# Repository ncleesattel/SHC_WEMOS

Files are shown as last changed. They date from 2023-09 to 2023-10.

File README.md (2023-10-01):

# SHC_WEMOS
This is a handheld controller for TeenAstro.  
See also [Link to TeenAstro Wiki](https://groups.io/g/TeenAstro/wiki) and [link to TeenAstro github](https://github.com/charleslemaire0/TeenAstro)   
  
It features a 3.3V OLED 2.42" display, a joystick together with the WEMOS D1 mini MCU.  
The associated pcb can be ordered at JLCPCB fully assembled with smd parts and JST XH connectors.  
This reduces the amount of soldering to a minimum.  
  
I also provide a design of an OLED pcb, that does not require smd soldering for the I2C use compared to the DIYmore pcb.  
Costs for the separate OLED pcb are about 3x, which makes it interesting only for hobbyists who want to avoid the smd solder.

## recommendations
* You’ll need to be able to solder a connection using a pinheader between the two pcbs.
* You’ll also need the soldering iron to melt the Ruthex nuts into place.
* The 3D prints do not need supports. Depending on your printer you may need to scale by 1.015 to account for thermal shrink.
* The cable length should be properly sized. The case does not have much room to accommodate long cables, however short cables make assembly and disassembly more difficult.
* Although the JST XH connectors can be attached to the cables without a crimp tool, I would highly recommend one for ease of life. You can thank me later.
*Check the functionality and connector sequence/polarity prior to assembly.

## components needed for build
* PCB group
  * pcb incl. smd parts of SHC
  * pcb for OLED 2.42“. Either mine with switches for I2C or DIYmore incl. smd modification
  * OLED 2.42“ display
  * metal bracket to attach OLED display to OLED pcb
* 3D print group
  * 3d print for pcb to display spacer
  * 3d print of bottom part
  * 3d print of top cover
  * Ruthex M3 nuts 2x
* Switches and cables
  * APEM 1000 joystick
  * APEM 1212 switch for shift
  * RAFI switches for focusser
  * SAL8 connector
  * JST XH connectors

## which files are needed for the...
* pcbs
  * SHC pcb --> jlcpcb folder
  * OLED pcb --> separate repository
* 3D prints
  * SHC bottom case --> models folder
  * SHC top case --> models folder
  * SHC display to pcb spacer --> models folder
 
 ## associated CAD files
The CAD files have been mostly created in Fusion 360 with OEM parts imported where available.

## approximate cost
The cost is calculated for a single SHC, assuming the pcb cost of 5 can be shared.
Shipping costs are included for 2x JLCPCB and 1x Reichelt.

| Parts | Cost |
|---|---|
| WEMOS D1 mini | 6€ |
| 3d printed parts | 40€ |
| SHC pcb | 8€ |
| OLED pcb | 8€ |
| OLED with frame | 18€ |
| APEM joystick | 32€ |
| RAFI and APEM switches | 9€ |
| Remainder | 10€ |
| Total | 131€ |

Depending on if you have access to a 3d printer and can share the pcb cost, you're looking the following range:
minimal build cost 90€ (own 3d printer and can share pcb cost)
maximal build cost 180€ (have to order the 3d case stls and cannot share pcb cost)

## pictures of the SHC
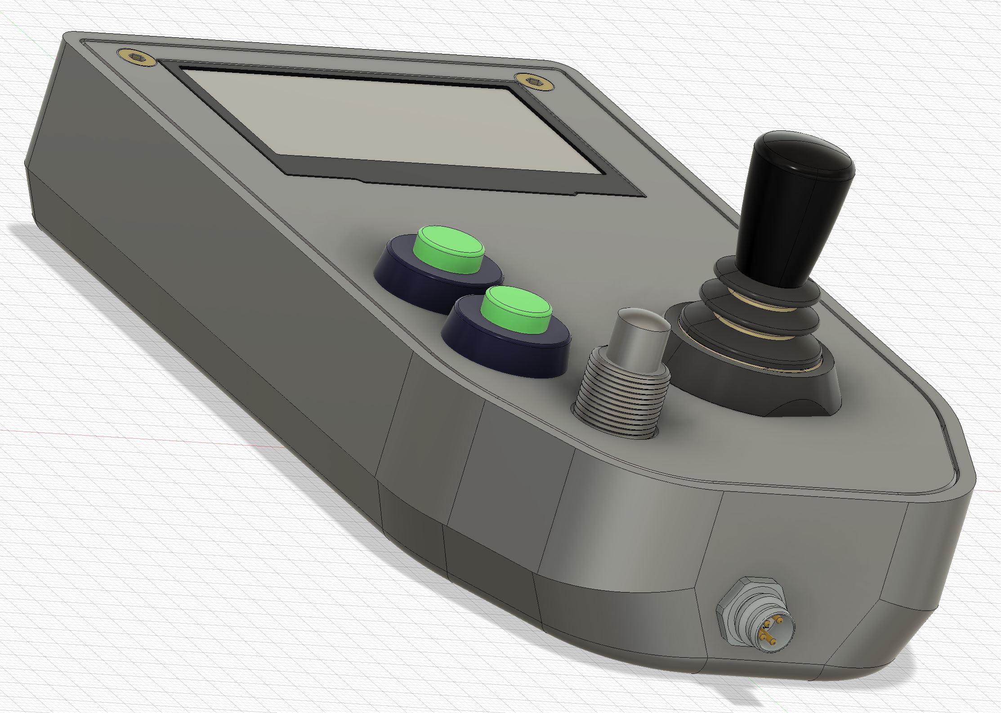
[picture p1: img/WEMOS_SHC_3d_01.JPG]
SHC_WEMOS 3D view WEMOS_SHC_3d_01


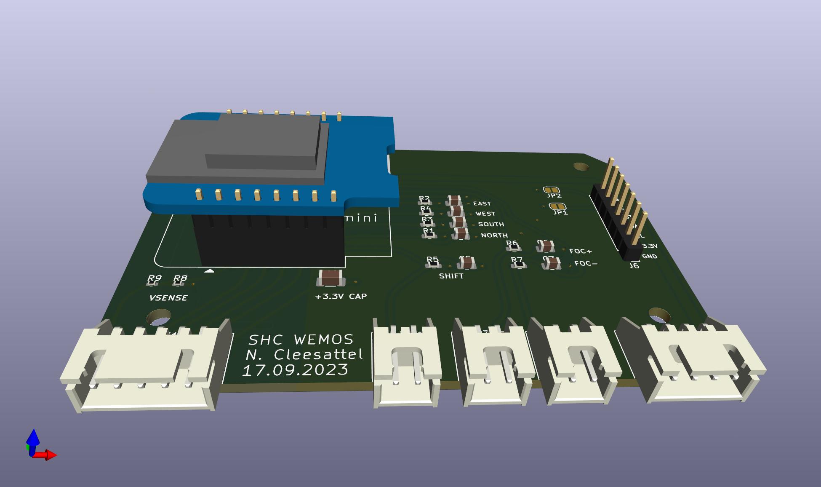
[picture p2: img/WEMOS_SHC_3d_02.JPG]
SHC_WEMOS pcb view WEMOS_SHC_3d_02


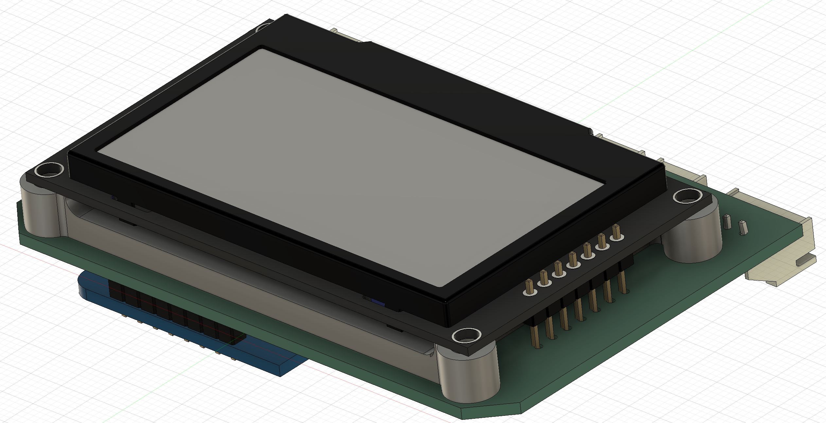
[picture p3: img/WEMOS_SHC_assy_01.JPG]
SHC_WEMOS assembly step 01 WEMOS_SHC_assy_01


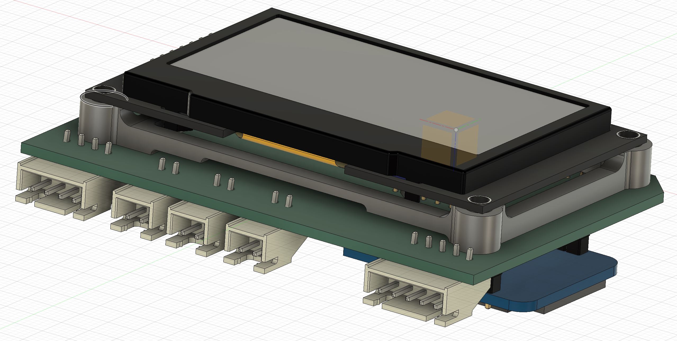
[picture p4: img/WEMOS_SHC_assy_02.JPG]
SHC_WEMOS assembly step 02 WEMOS_SHC_assy_02


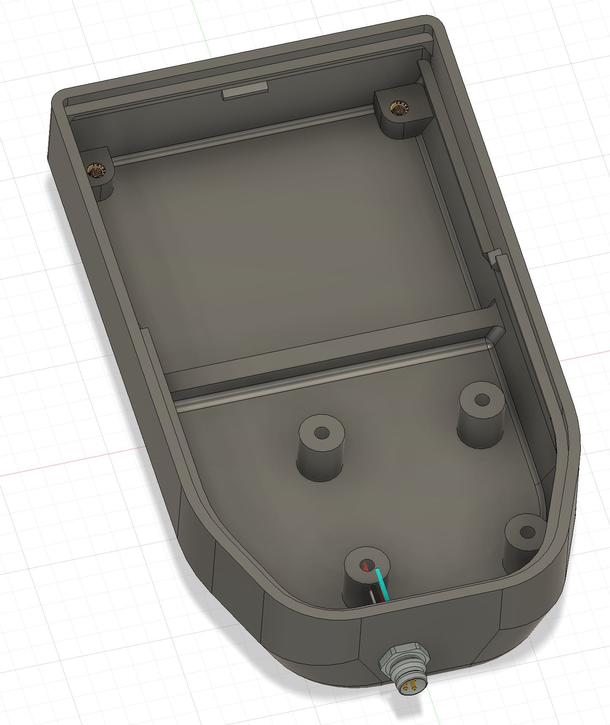
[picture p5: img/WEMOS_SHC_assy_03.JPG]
SHC_WEMOS assembly step 03 WEMOS_SHC_assy_03


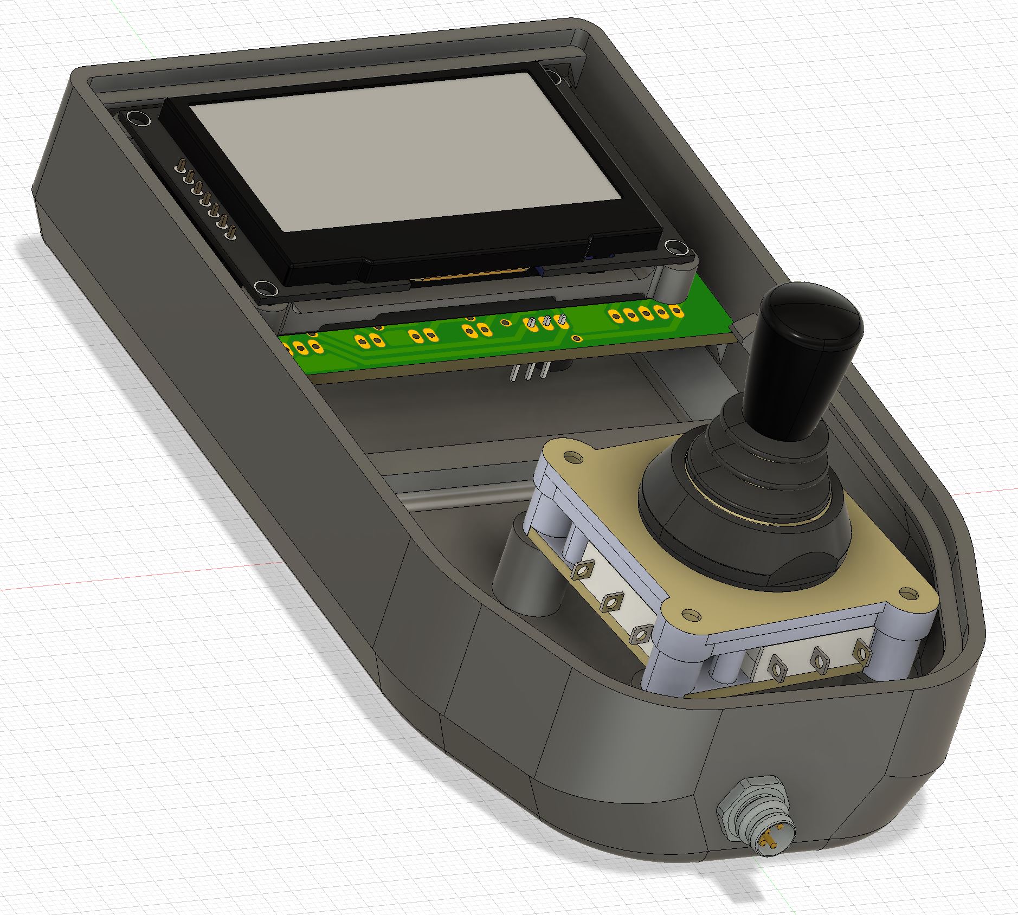
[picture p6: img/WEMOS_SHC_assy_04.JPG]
SHC_WEMOS assembly step 04 WEMOS_SHC_assy_04


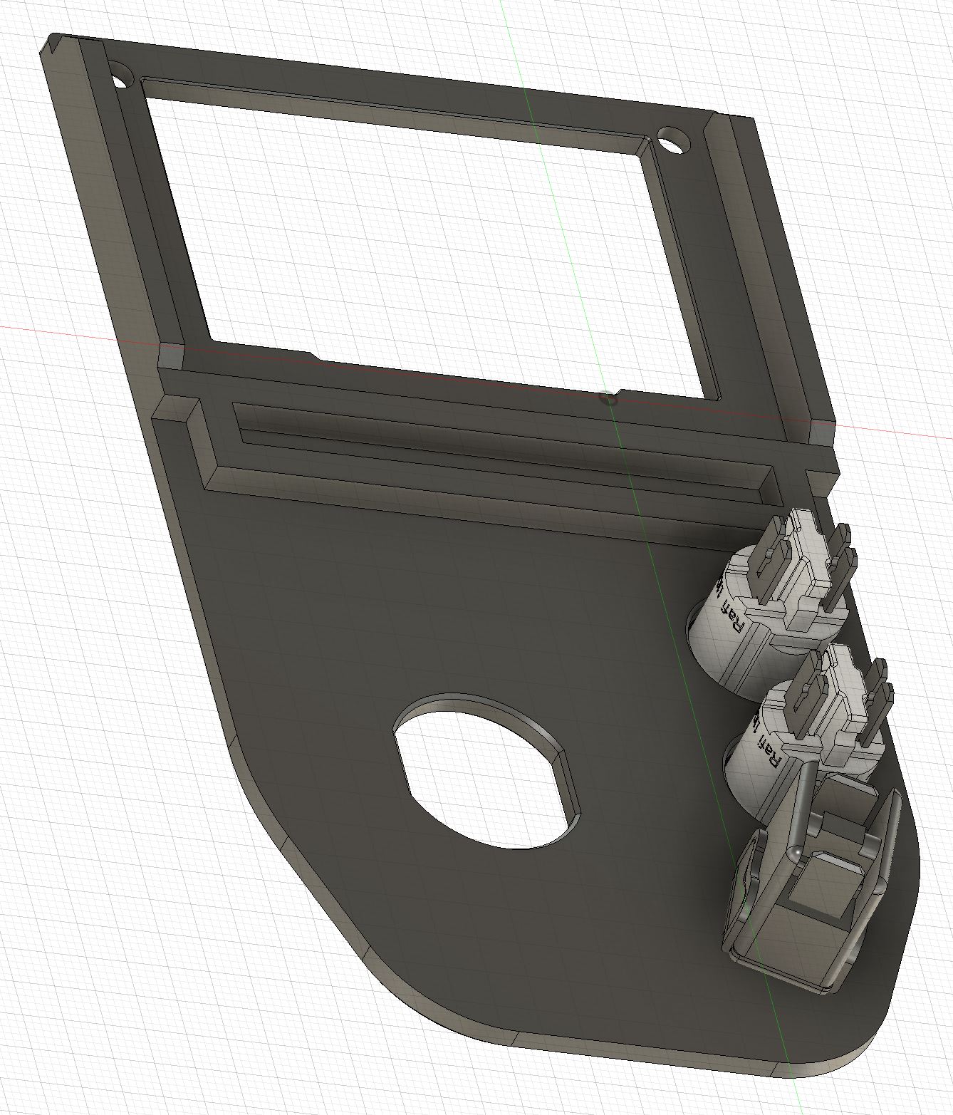
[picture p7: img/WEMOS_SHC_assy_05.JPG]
SHC_WEMOS assembly step 05 WEMOS_SHC_assy_05


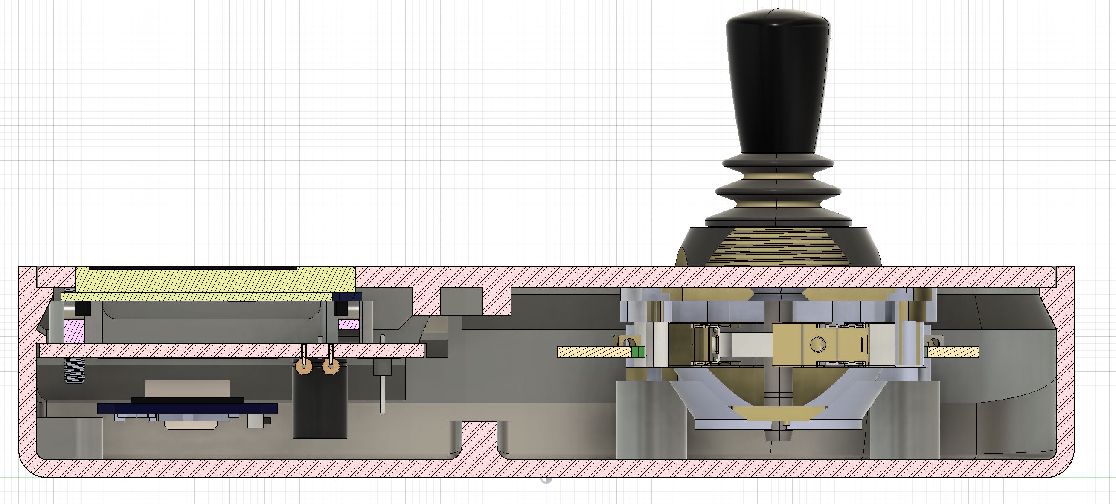
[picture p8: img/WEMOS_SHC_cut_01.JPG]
SHC_WEMOS side view cut WEMOS_SHC_cut_01


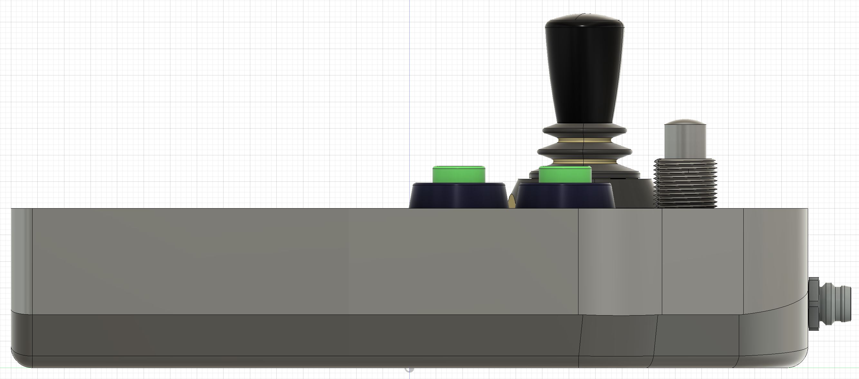
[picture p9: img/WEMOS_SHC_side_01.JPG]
SHC_WEMOS side view WEMOS_SHC_side_01


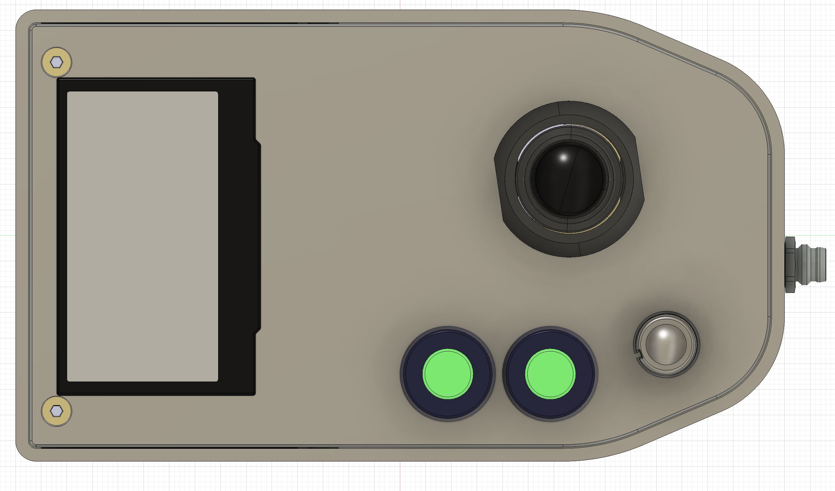
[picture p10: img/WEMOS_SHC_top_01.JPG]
SHC_WEMOS top view WEMOS_SHC_top_01


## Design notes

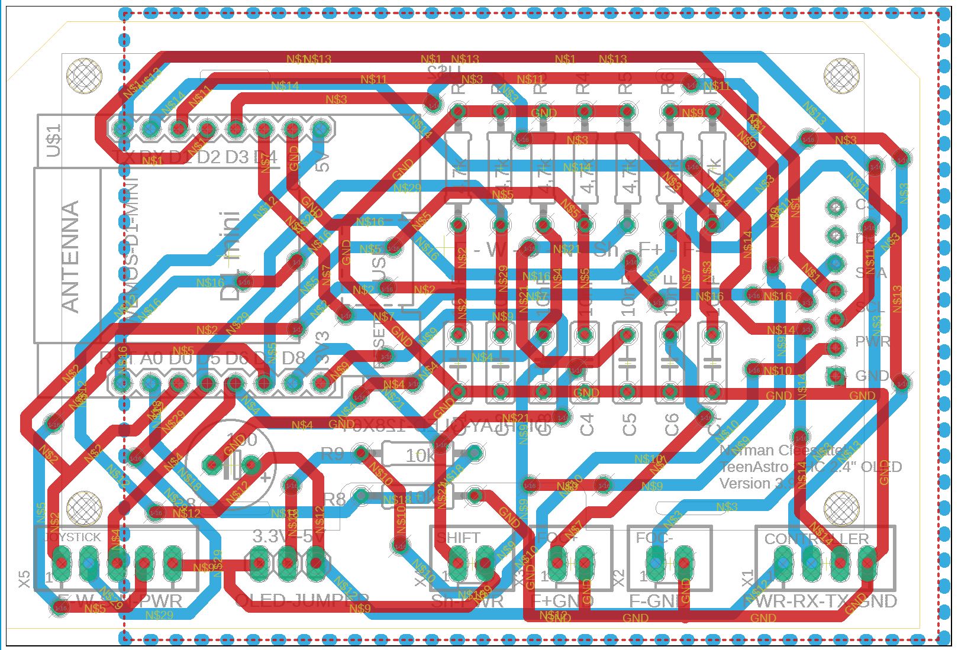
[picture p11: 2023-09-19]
import/Eagle_BRDfile.JPG

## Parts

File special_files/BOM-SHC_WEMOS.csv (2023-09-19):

Comment | Designator | Footprint | LCSC
100uF | C8 | C_1206_3216Metric | C15008
MainUnit | J5 | JST_XH_S4B-XH-A_1x04_P2.50mm_Horizontal | C157925
Shift | J2,J3,J4 | JST_XH_S2B-XH-A_1x02_P2.50mm_Horizontal | C157931
10nF | C1,C2,C3,C4,C5,C6,C7 | C_0805_2012Metric | C1710
10k | R8,R9 | R_0402_1005Metric | C25744
4.7k | R1,R2,R3,R4,R5,R6,R7 | R_0603_1608Metric | C25999
Joystick | J1 | JST_XH_S5B-XH-A_1x05_P2.50mm_Horizontal | C263757
WemosPinsL | J7,J8 | PinSocket_1x08_P2.54mm_Vertical | C27438

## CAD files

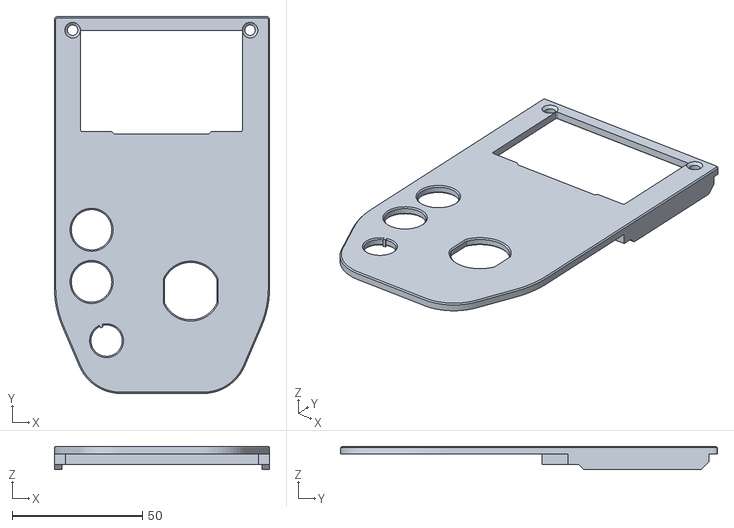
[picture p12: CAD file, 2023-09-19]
models/SHC_WEMOS_top.stl
82.5 x 144.5 x 9.00

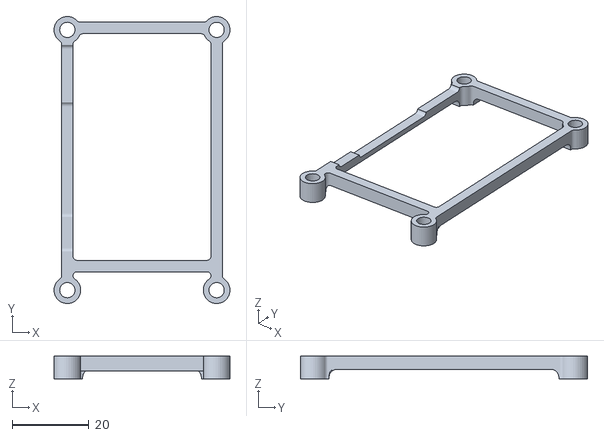
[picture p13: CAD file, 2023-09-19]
models/SHC_Frame.stl
46.0 x 75.0 x 6.00

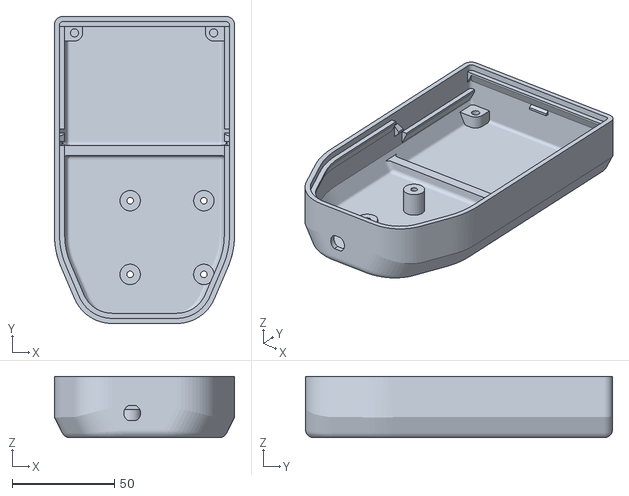
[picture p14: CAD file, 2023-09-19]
models/SHC_WEMOS_bottom.stl
88.0 x 150.0 x 30.0

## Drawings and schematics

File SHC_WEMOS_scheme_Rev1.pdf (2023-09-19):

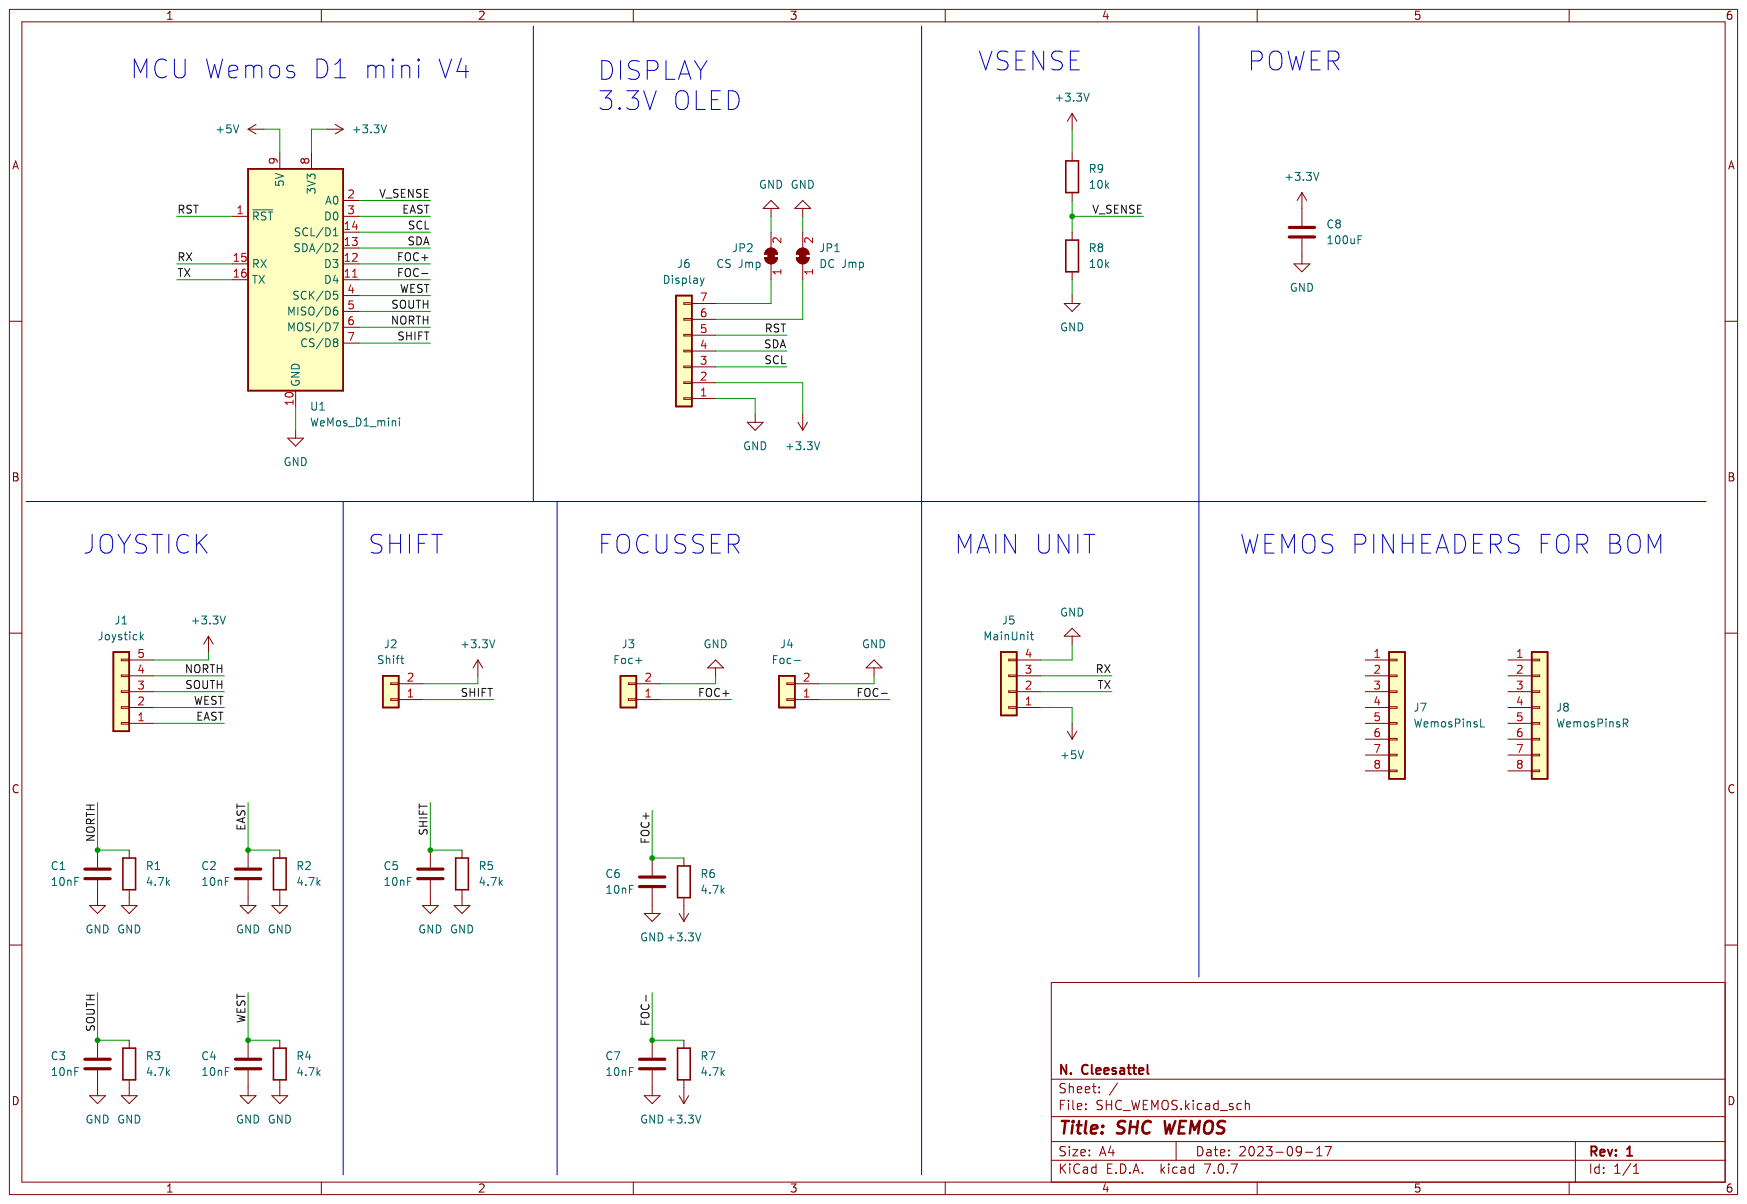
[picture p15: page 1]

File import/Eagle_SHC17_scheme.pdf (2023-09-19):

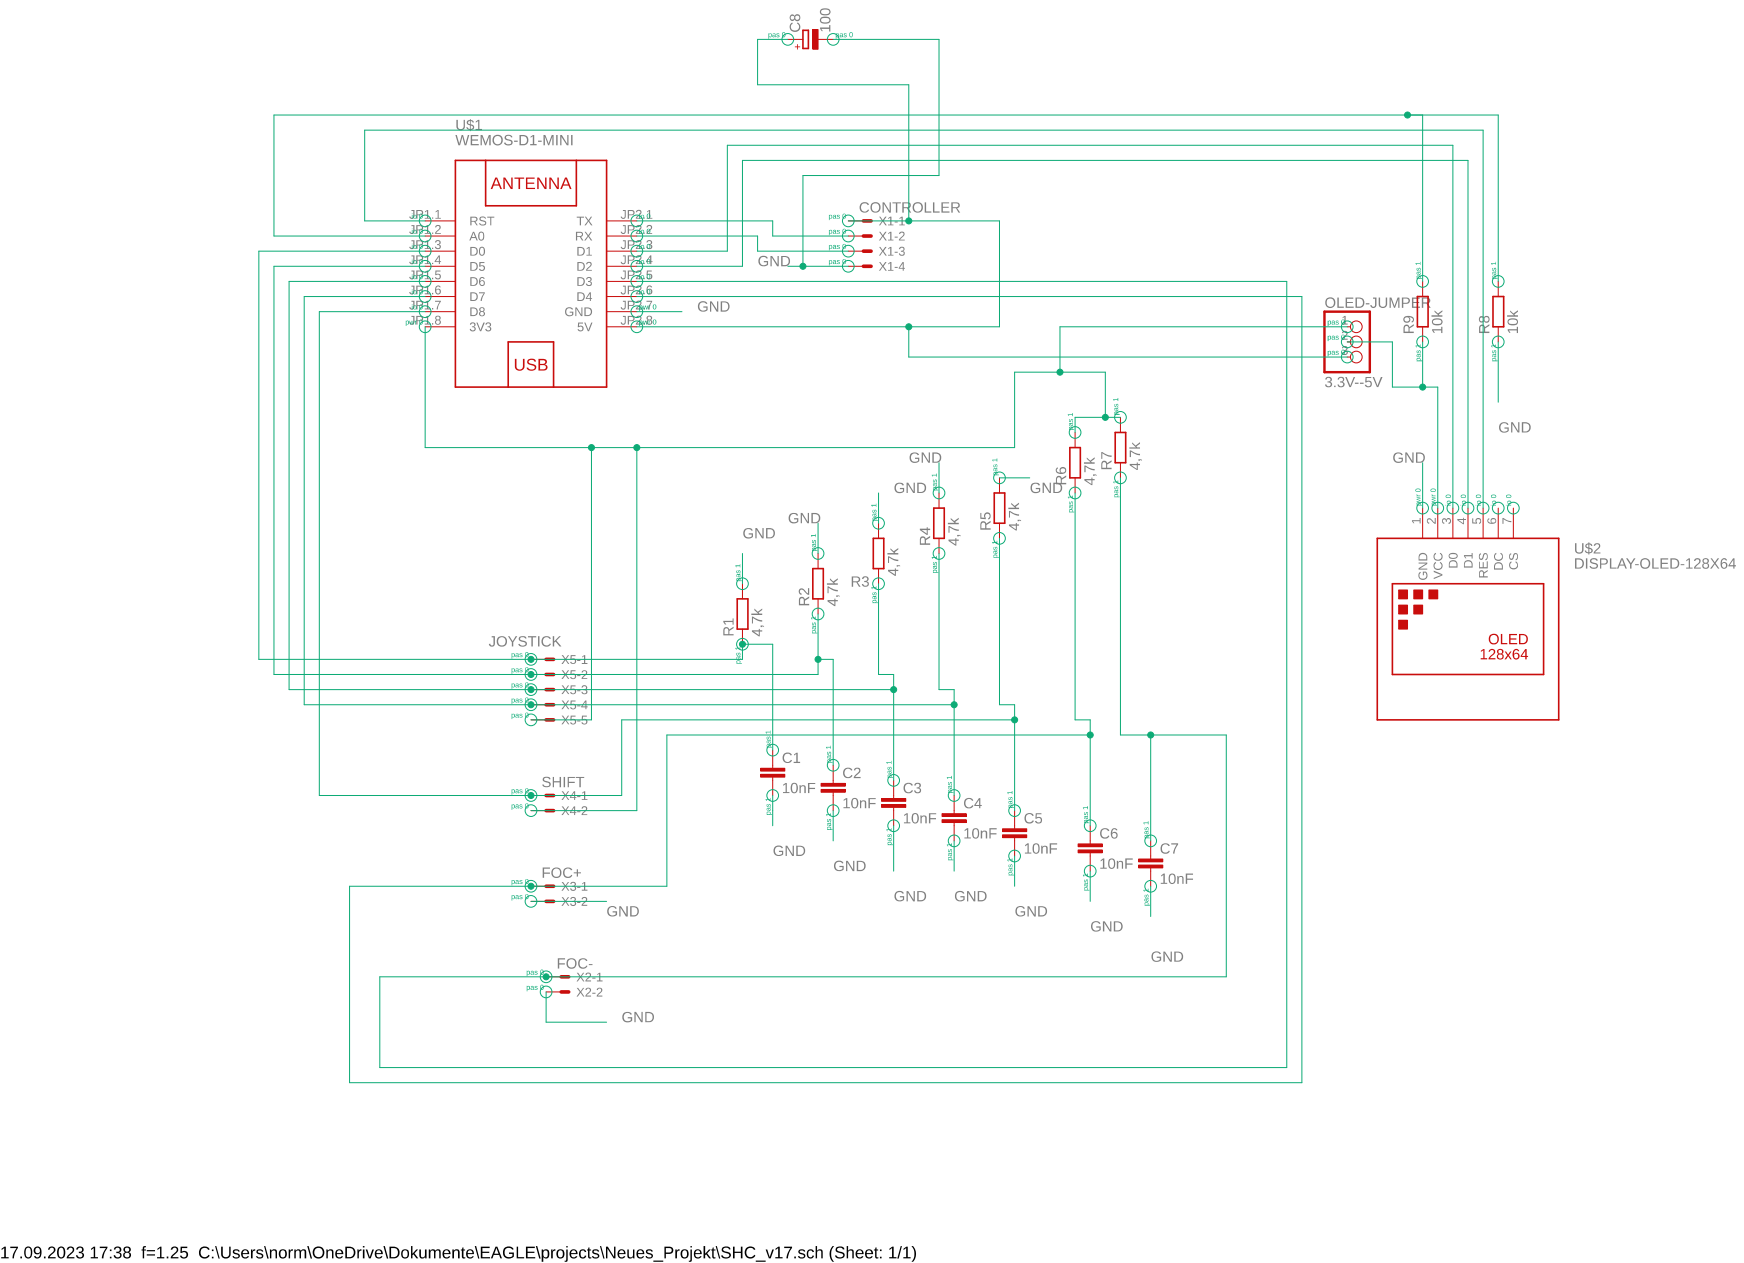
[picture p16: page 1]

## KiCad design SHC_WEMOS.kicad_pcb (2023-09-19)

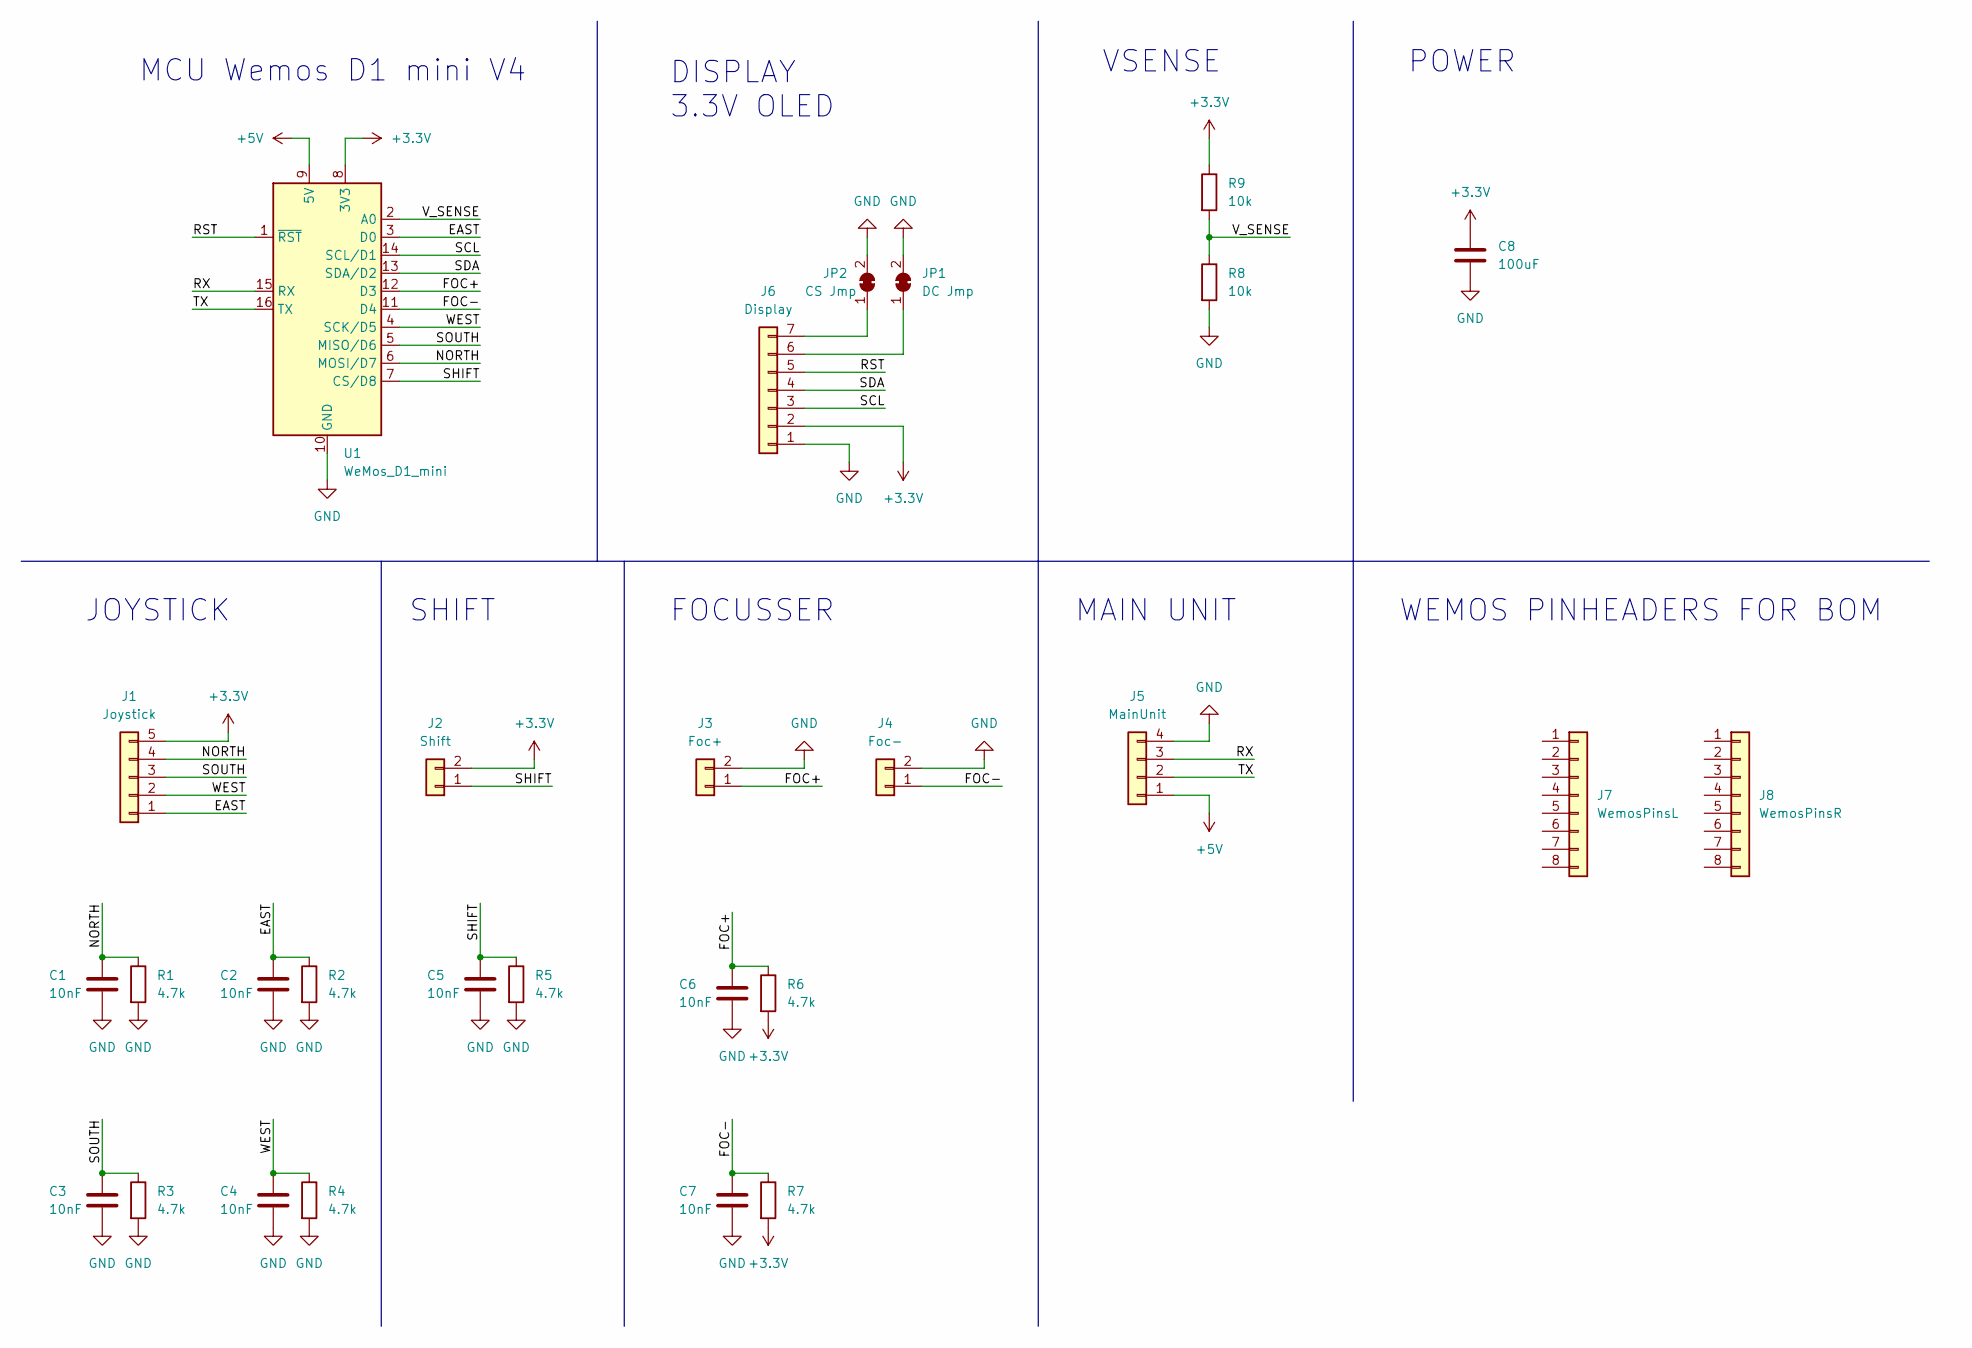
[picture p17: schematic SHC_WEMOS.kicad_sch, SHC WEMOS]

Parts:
C1, C2, C3, C4, C5, C6, C7: 10nF; C_0805_2012Metric; LCSC C1710
C8: 100uF; C_1206_3216Metric; LCSC C15008
J1: Joystick; JST_XH_S5B-XH-A_1x05_P2.50mm_Horizontal; LCSC C263757
J2: Shift; JST_XH_S2B-XH-A_1x02_P2.50mm_Horizontal; LCSC C157931
J3: Foc+; JST_XH_S2B-XH-A_1x02_P2.50mm_Horizontal; LCSC C157931
J4: Foc-; JST_XH_S2B-XH-A_1x02_P2.50mm_Horizontal; LCSC C157931
J5: MainUnit; JST_XH_S4B-XH-A_1x04_P2.50mm_Horizontal; LCSC C157925
J6: Display; PinHeader_1x07_P2.54mm_Vertical
J7: WemosPinsL; PinSocket_1x08_P2.54mm_Vertical; LCSC C27438
J8: WemosPinsR; PinSocket_1x08_P2.54mm_Vertical; LCSC C27438
JP1: DC Jmp; SolderJumper-2_P1.3mm_Bridged_RoundedPad1.0x1.5mm
JP2: CS Jmp; SolderJumper-2_P1.3mm_Bridged_RoundedPad1.0x1.5mm
R1, R2, R3, R4, R5, R6, R7: 4.7k; R_0603_1608Metric; LCSC C25999
R8, R9: 10k; R_0402_1005Metric; LCSC C25744
U1: WeMos_D1_mini; WEMOS_D1_mini_light

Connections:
+3.3V: C8.1, J1.5, J2.2, J6.2, R6.2, R7.2, R9.1, U1.8 (3V3)
+5V: J5.1, U1.9 (5V)
/EAST: C2.1, J1.1, R2.1, U1.3 (D0)
/FOC+: C6.1, J3.1, R6.1, U1.12 (D3)
/FOC-: C7.1, J4.1, R7.1, U1.11 (D4)
/NORTH: C1.1, J1.4, R1.1, U1.6 (MOSI/D7)
/RST: J6.5, U1.1 (~RST)
/RX: J5.3, U1.15 (RX)
/SCL: J6.3, U1.14 (SCL/D1)
/SDA: J6.4, U1.13 (SDA/D2)
/SHIFT: C5.1, J2.1, R5.1, U1.7 (CS/D8)
/SOUTH: C3.1, J1.3, R3.1, U1.5 (MISO/D6)
/TX: J5.2, U1.16 (TX)
/V_SENSE: R8.1, R9.2, U1.2 (A0)
/WEST: C4.1, J1.2, R4.1, U1.4 (SCK/D5)
GND: C1.2, C2.2, C3.2, C4.2, C5.2, C6.2, C7.2, C8.2, J3.2, J4.2, J5.4, J6.1, JP1.2 (B), JP2.2 (B), R1.2, R2.2, R3.2, R4.2, R5.2, R8.2, U1.10 (GND)
unnamed: J6.6, JP1.1 (A)
unnamed: J6.7, JP2.1 (A)

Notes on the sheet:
MCU Wemos D1 mini V4
MAIN UNIT
SHIFT
FOCUSSER
VSENSE
DISPLAY 3.3V OLED
WEMOS PINHEADERS FOR BOM
JOYSTICK
POWER

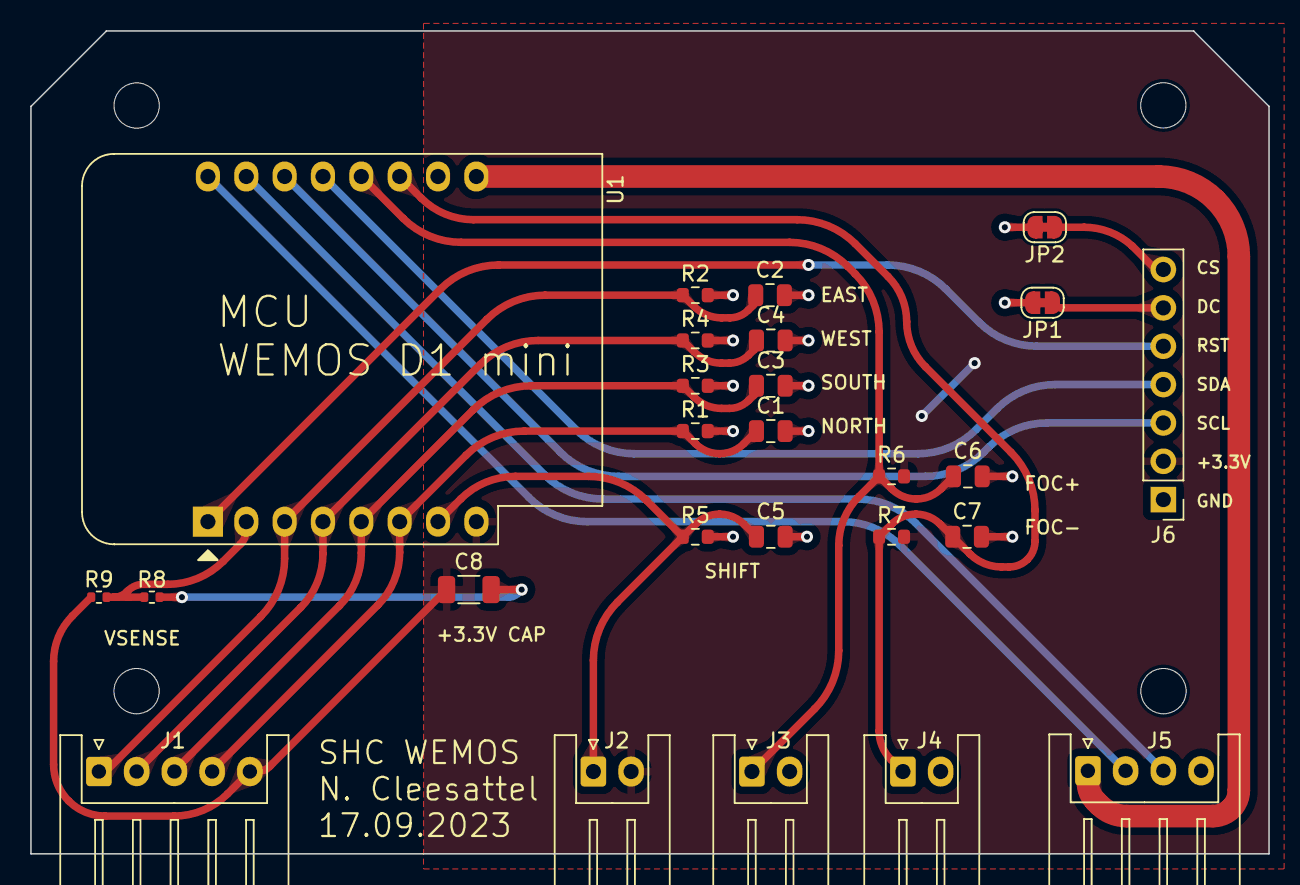
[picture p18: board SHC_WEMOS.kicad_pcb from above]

Board: 2 copper layers, 82.0 x 54.5 mm, 26 parts (0 on the bottom side), 18 nets.

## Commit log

2023-09-19 Initial release
    Initial release from private repository.
    [BOM-SHC_WEMOS.csv, SHC_Frame.stl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]
2023-09-19 Add electric scheme as PDF print from KiCad
